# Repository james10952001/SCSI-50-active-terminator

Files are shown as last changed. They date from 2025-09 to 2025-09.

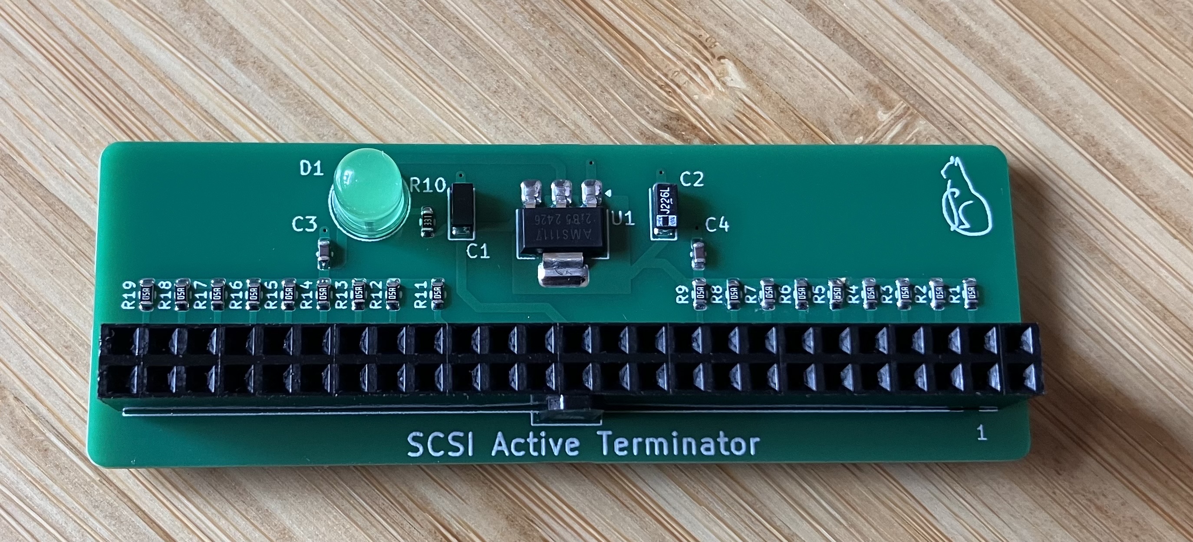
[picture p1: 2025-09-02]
SCSI Terminator.jpg

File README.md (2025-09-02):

# SCSI-50-active-terminator
Open source active terminator for 50 pin single ended SCSI systems. This is designed so it can be built with either the standard male connector that mates with 50 pin SCSI cables or the less common female connector needed by the OEM cable in my DECpc 486. The connector will need to be installed on the side of the board marked 'M' if you are using a male connector or 'F' if you use a female connector. The LED can be installed on either side according to preference. It is recommended to use an old style low efficiency LED to achieve a period correct look in your vintage machine, otherwise you should increase the value of R10 so that a modern LED is not obnoxiously bright.

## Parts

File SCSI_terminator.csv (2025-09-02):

Reference | Qty | Value | P/N
C1 | 1 | 10uF | TCA0J106M8R
C2 | 1 | 22uF | 293D226X96R3A2TE3
C3,C4 | 2 | 100n | CL10B104KB8NNWC
D1 | 1 | LED | LED THT 5.0mm
J1 | 1 | SCSI-50 | SBH11-PBPC-D25-ST-BK (Male) or https://www.ebay.com/itm/386230187881 (Female)
R1,R2,R3,R4,R5,R6,R7,R8,R9,R11,R12,R13,R14,R15,R16,R17,R18,R19 | 18 | 110R | RT0603FRE07110RL
R10 | 1 | 330R | RC0603JR-07330RL
U1 | 1 | AMS1117-2.85 | AMS1117-2.85 https://www.lcsc.com/product-detail/C14791.html

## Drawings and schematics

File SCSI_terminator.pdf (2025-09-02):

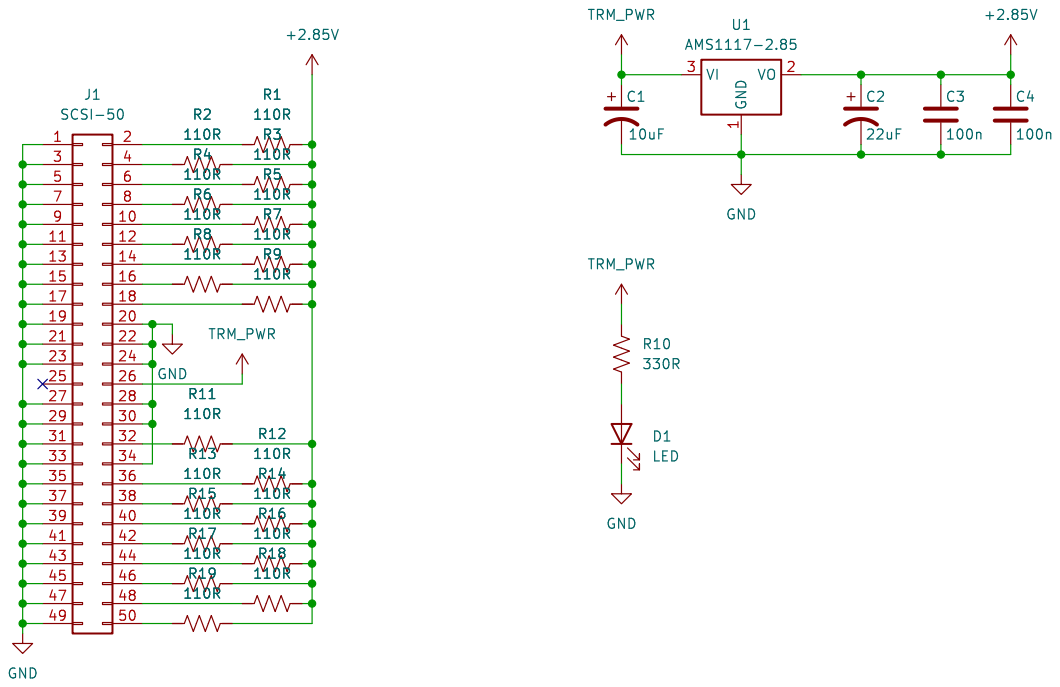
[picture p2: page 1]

Id: 1/1 Title: File: SCSI_terminator.kicad_sch Sheet: / GND

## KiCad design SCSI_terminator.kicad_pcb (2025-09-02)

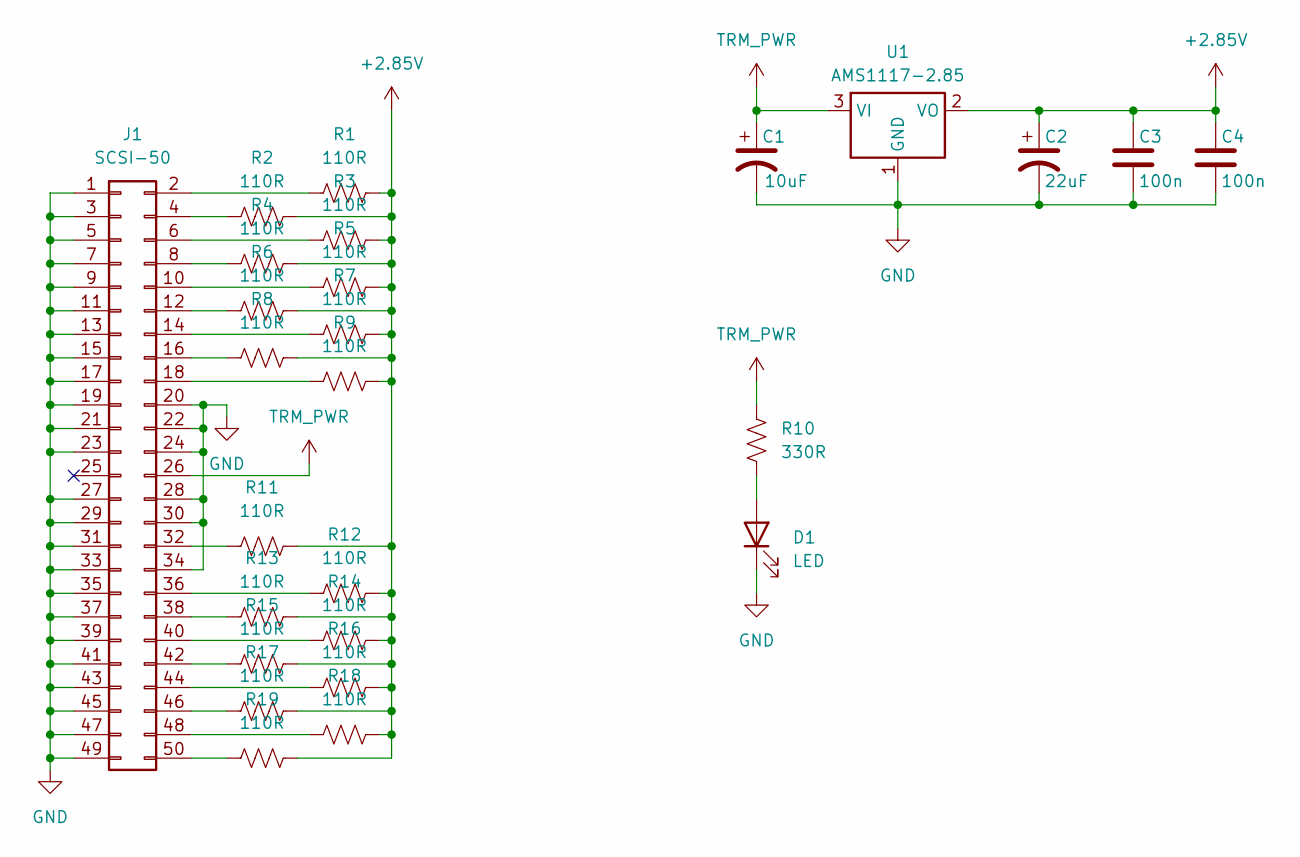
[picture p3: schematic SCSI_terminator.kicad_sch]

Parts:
C1: 10uF; CP_EIA-3216-18_Kemet-A
C2: 22uF; CP_EIA-3216-18_Kemet-A
C3, C4: 100n; C_0603_1608Metric
D1: LED; LED_D5.0mm
J1: SCSI-50; PinHeader_2x25_P2.54mm_Vertical
R1, R2, R3, R4, R5, R6, R7, R8, R9, R11, R12, R13, R14, R15, R16, R17, R18, R19: 110R; R_0603_1608Metric
R10: 330R; R_0603_1608Metric
U1: AMS1117-2.85; SOT-223-3_TabPin2

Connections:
+2.85V: C2.1, C3.1, C4.1, R1.2, R2.2, R3.2, R4.2, R5.2, R6.2, R7.2, R8.2, R9.2, R11.2, R12.2, R13.2, R14.2, R15.2, R16.2, R17.2, R18.2, R19.2, U1.2 (VO)
GND: C1.2, C2.2, C3.2, C4.2, D1.1 (K), J1.1, J1.3, J1.5, J1.7, J1.9, J1.11, J1.13, J1.15, J1.17, J1.19, J1.20, J1.21, J1.22, J1.23, J1.24, J1.27, J1.28, J1.29, J1.30, J1.31, J1.33, J1.34, J1.35, J1.37, J1.39, J1.41, J1.43, J1.45, J1.47, J1.49, U1.1 (GND)
unnamed: D1.2 (A), R10.1
unnamed: J1.2, R1.1
unnamed: J1.4, R2.1
unnamed: J1.6, R3.1
unnamed: J1.8, R4.1
unnamed: J1.10, R5.1
unnamed: J1.12, R6.1
unnamed: J1.14, R7.1
unnamed: J1.16, R8.1
unnamed: J1.18, R9.1
unnamed: J1.32, R11.1
unnamed: J1.36, R12.1
unnamed: J1.38, R13.1
unnamed: J1.40, R14.1
unnamed: J1.42, R15.1
unnamed: J1.44, R16.1
unnamed: J1.46, R17.1
unnamed: J1.48, R18.1
unnamed: J1.50, R19.1
TRM_PWR: C1.1, J1.26, R10.2, U1.3 (VI)

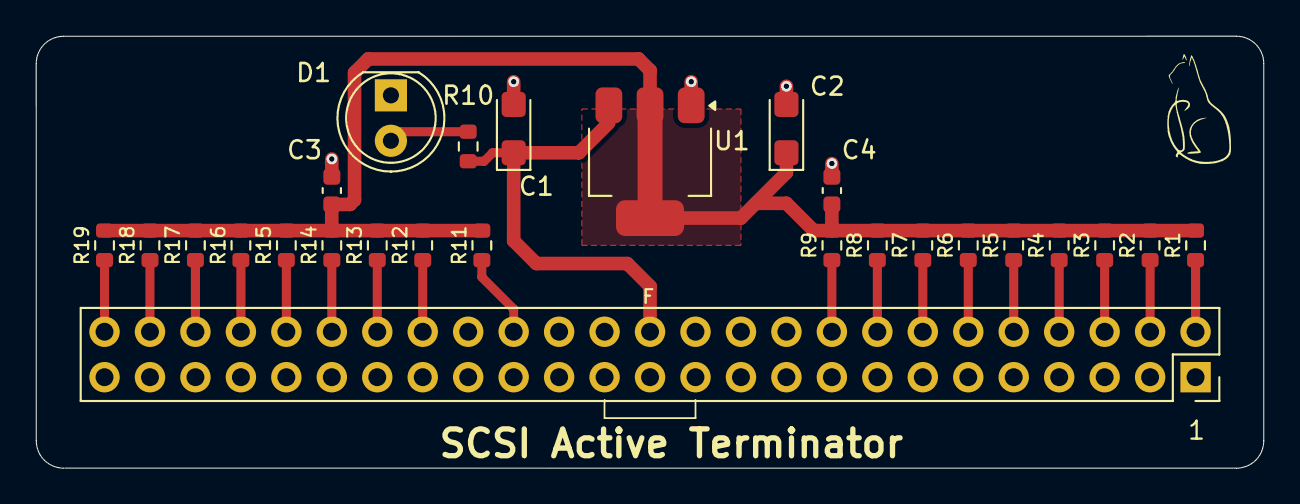
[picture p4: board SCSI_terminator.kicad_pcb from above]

Board: 2 copper layers, 68.6 x 24.1 mm, 27 parts (1 on the bottom side), 22 nets.

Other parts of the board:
VAL: REF; cat_300

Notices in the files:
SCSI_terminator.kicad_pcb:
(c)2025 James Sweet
